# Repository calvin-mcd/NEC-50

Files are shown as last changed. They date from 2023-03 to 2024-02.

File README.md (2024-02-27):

# NEC-50

NEC-50 is a katana stagger keyboard pcb using the micro controller [rp2040-zero](https://www.waveshare.com/rp2040-zero.htm) and taking heavy inspiration from the [NEC PC-9801](http://xahlee.info/kbd/nec_m_type_1992.html)

## Layout

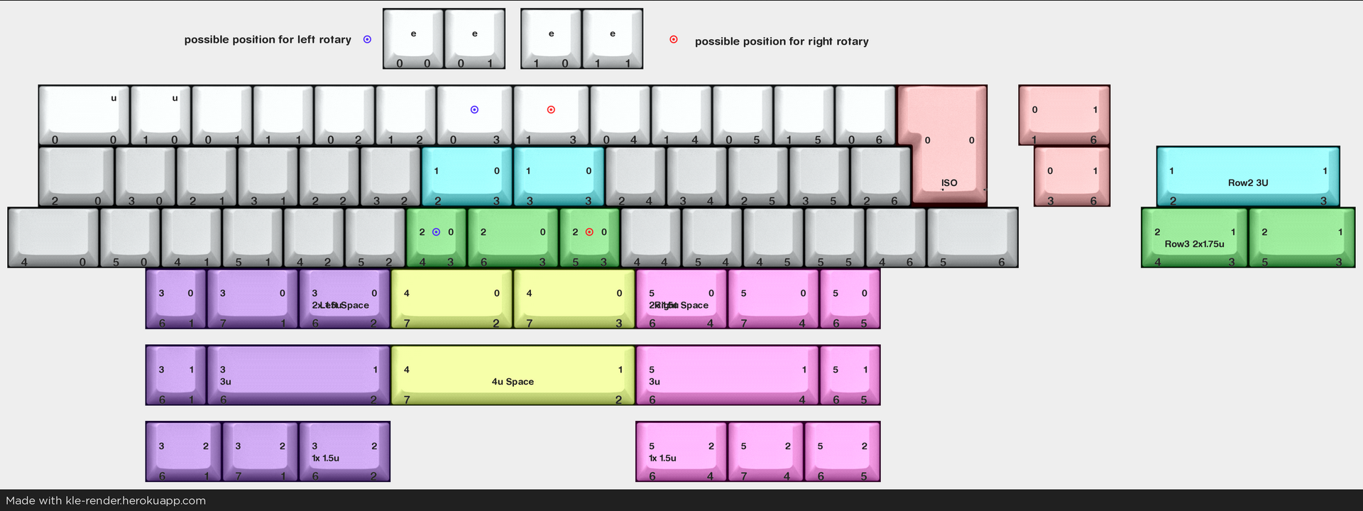
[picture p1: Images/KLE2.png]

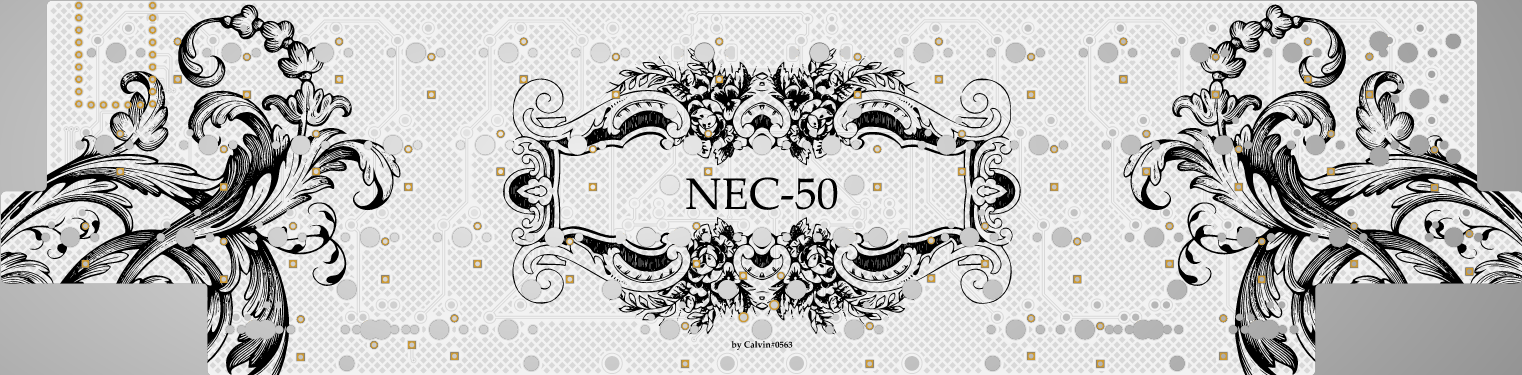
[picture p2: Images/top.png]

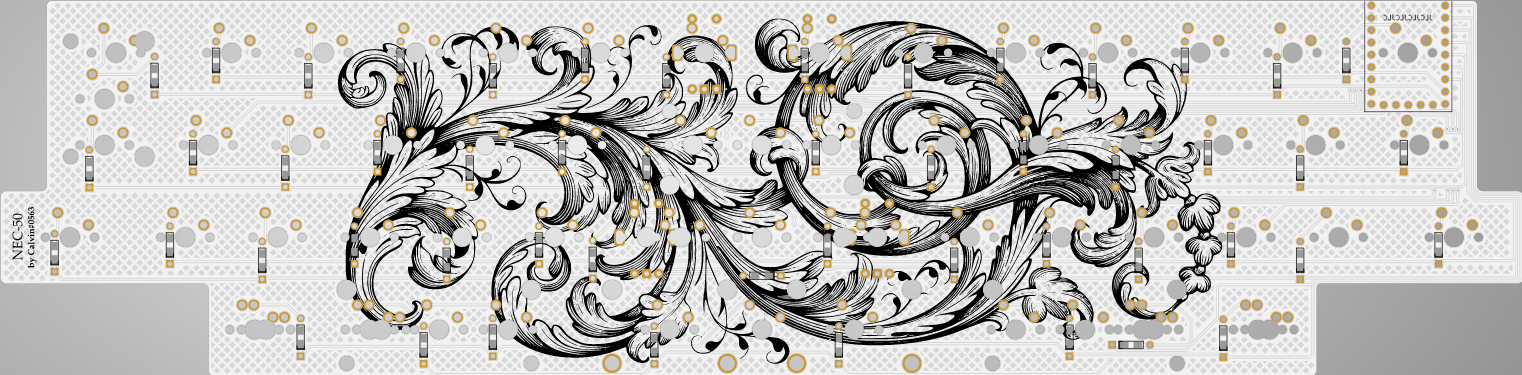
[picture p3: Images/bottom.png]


[Link](http://www.keyboard-layout-editor.com/#/gists/75caf7895b6885905f6ad9112279089a)

## Cases

There are two cases for the NEC-50 so far:

- BAonDiscord#7634's custom case is called the N0550 and takes inspiration from the M0110.



https://github.com/ba-keyboards/N0550

check out their other amazing cases here: https://ba-keyboards.github.io/

- dingusaurusderp's case is called the Hotdog stand (lol) and is a two piece and can also support a weight if desired!

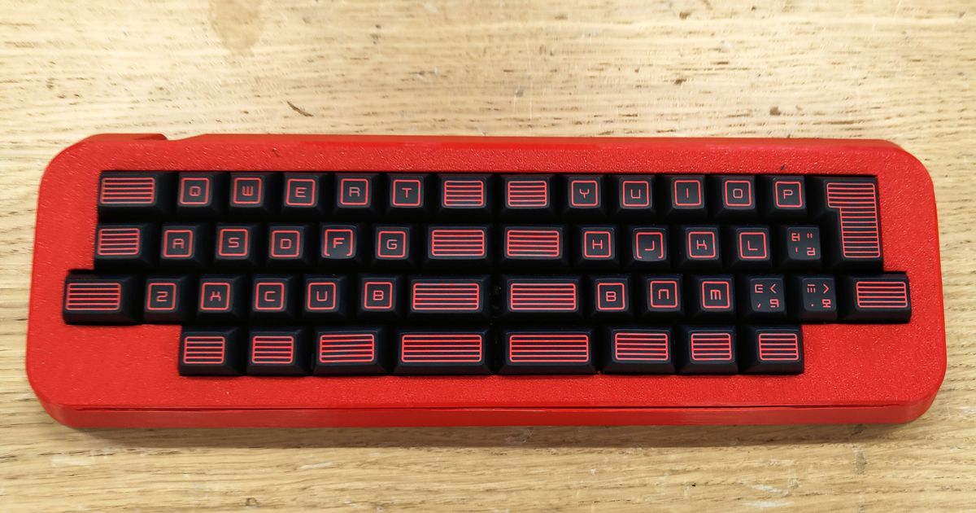
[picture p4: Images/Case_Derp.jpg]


https://www.printables.com/de/model/784448-hotdog-stand-nec-50-case
  
## Disclaimer

The PCB and case files has been fully tested and confirmed to work. The members of the PCB development team are however not liable if you end up with a non-functional pcb. Order at your own risk. Support will not be provided but pull requests will be reviewed and possibly accepted.

## License

This project is released under the GPL v3 License. Please refer to the LICENCE file.

## Credits

big thanks to both BAonDiscord#7634 and dingusaurusderp for taking their time to create unqiue cases for something that started out as more of a joke! love the 40s community!

also many thanks to haizeus for helping with the KLE and firmware!

As always big thanks also to the many people who inspired and helped with this board!

Any questions, contact Calvin\#0563 on Discord.

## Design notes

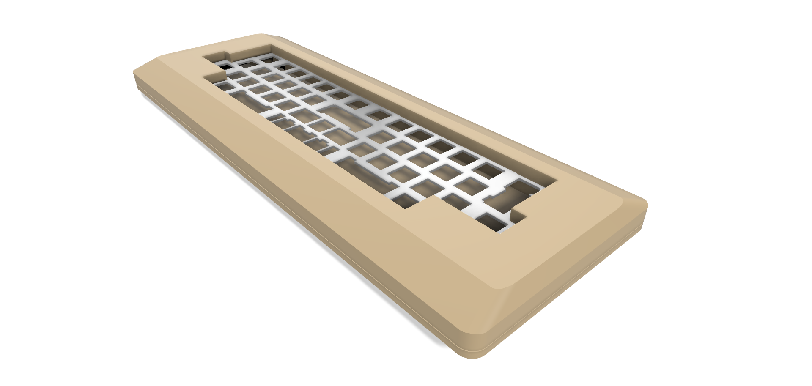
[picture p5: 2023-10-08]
Images/Case - M0110 - 1.png

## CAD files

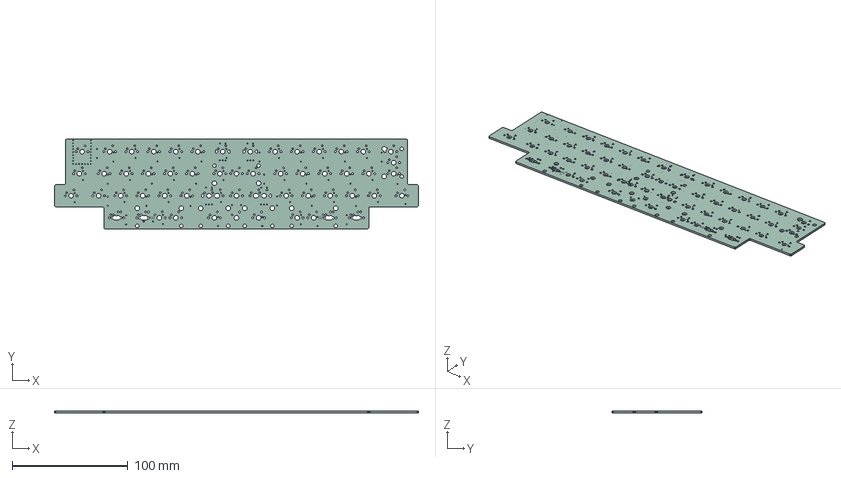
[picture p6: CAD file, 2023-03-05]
Project/NEC.step
314.3 x 77.5 x 1.60 mm

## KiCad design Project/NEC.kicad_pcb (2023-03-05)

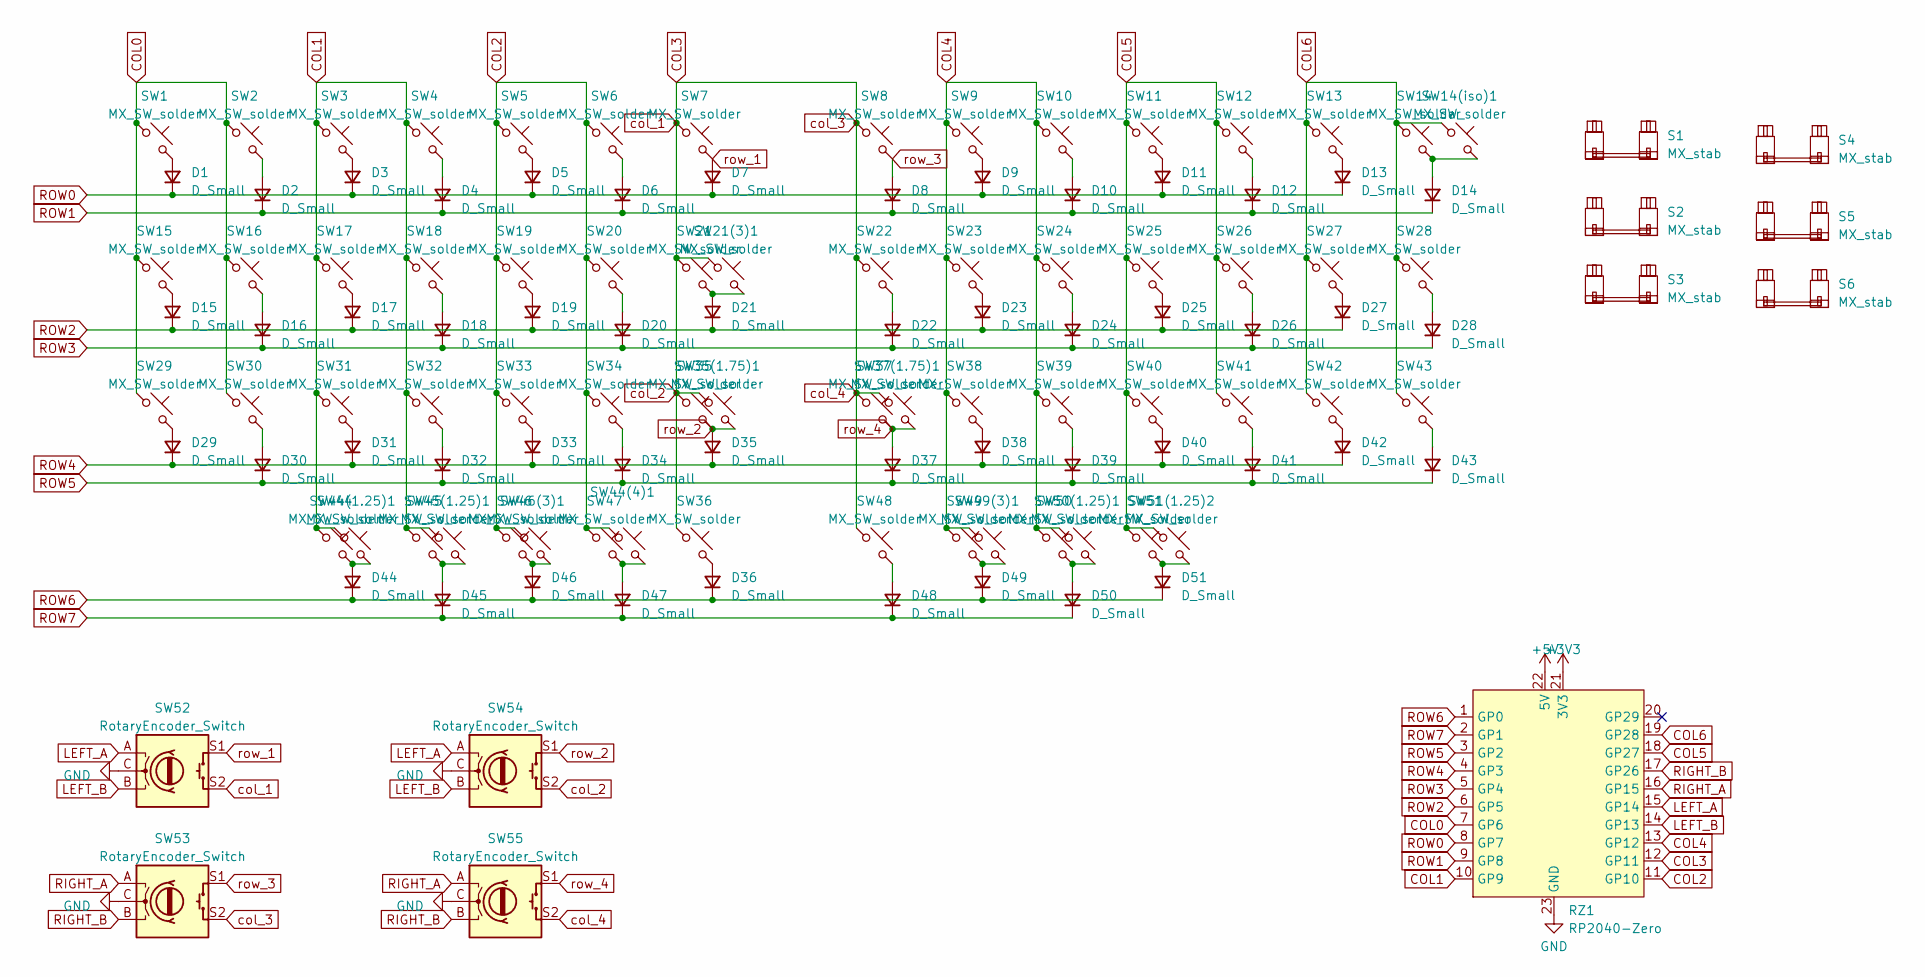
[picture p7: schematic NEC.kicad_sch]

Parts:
D1, D2, D3, D4, D5, D6, D7, D8, D9, D10, D11, D12, D13, D14, D15, D16, D17, D18, D19, D20, D21, D22, D23, D24, D25, D26, D27, D28, D29, D30, D31, D32, D33, D34, D35, D36, D37, D38, D39, D40, D41, D42, D43, D44, D45, D46, D47, D48, D49, D50, D51: D_Small; Diode-Hybrid-Back
RZ1: RP2040-Zero
S1, S2: MX_stab; STAB_MX_P_2u
S3, S4, S5: MX_stab; STAB_MX_3u
S6: MX_stab; STAB_MX_ISO_FLIPPED
SW1, SW14, SW21, SW22, SW29, SW36, SW43, SW45, SW46, SW49, SW50: MX_SW_solder; SW_MX_1.5u
SW2, SW3, SW4, SW5, SW6, SW9, SW10, SW11, SW12, SW13, SW14(iso)1, SW16, SW17, SW18, SW19, SW20, SW21(3)1, SW23, SW24, SW25, SW26, SW27, SW30, SW31, SW32, SW33, SW34, SW35, SW37, SW38, SW39, SW40, SW41, SW42, SW44, SW46(3)1, SW47, SW48, SW49(3)1, SW51: MX_SW_solder; SW_MX_1u
SW7, SW8, SW15, SW28, SW44(1.25)1, SW45(1.25)1, SW50(1.25)1, SW51(1.25)2: MX_SW_solder; SW_MX_1.25u
SW35(1.75)1, SW37(1.75)1: MX_SW_solder; SW_MX_1.75u
SW44(4)1: SW_Push_45deg; CherryMX_4.00u
SW52, SW53, SW54, SW55: RotaryEncoder_Switch; ROT_Alps_EC11E-Switch

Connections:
+3V3: RZ1.21 (3V3)
+5V: RZ1.22 (5V)
COL0: RZ1.7 (GP6), SW1.1, SW2.1, SW15.1, SW16.1, SW29.1, SW30.1
COL1: RZ1.10 (GP9), SW3.1, SW4.1, SW17.1, SW18.1, SW31.1, SW32.1, SW44.1, SW44(1.25)1.1, SW45.1, SW45(1.25)1.1
COL2: RZ1.11 (GP10), SW5.1, SW6.1, SW19.1, SW20.1, SW33.1, SW34.1, SW44(4)1.1, SW46.1, SW46(3)1.1, SW47.1
COL3: RZ1.12 (GP11), SW7.1, SW8.1, SW21.1, SW21(3)1.1, SW22.1, SW35.1, SW35(1.75)1.1, SW36.1, SW37.1, SW37(1.75)1.1, SW48.1, SW52.S2, SW53.S2, SW54.S2, SW55.S2
COL4: RZ1.13 (GP12), SW9.1, SW10.1, SW23.1, SW24.1, SW38.1, SW39.1, SW49.1, SW49(3)1.1, SW50.1, SW50(1.25)1.1
COL5: RZ1.18 (GP27), SW11.1, SW12.1, SW25.1, SW26.1, SW40.1, SW41.1, SW51.1, SW51(1.25)2.1
COL6: RZ1.19 (GP28), SW13.1, SW14.1, SW14(iso)1.1, SW27.1, SW28.1, SW42.1, SW43.1
GND: RZ1.23 (GND), SW52.C, SW53.C, SW54.C, SW55.C
LEFT_A: RZ1.15 (GP14), SW52.A, SW54.A
LEFT_B: RZ1.14 (GP13), SW52.B, SW54.B
unnamed: D1.2 (A), SW1.2
unnamed: D2.2 (A), SW2.2
unnamed: D3.2 (A), SW3.2
unnamed: D4.2 (A), SW4.2
unnamed: D5.2 (A), SW5.2
unnamed: D6.2 (A), SW6.2
unnamed: D9.2 (A), SW9.2
unnamed: D10.2 (A), SW10.2
unnamed: D11.2 (A), SW11.2
unnamed: D12.2 (A), SW12.2
unnamed: D13.2 (A), SW13.2
unnamed: D14.2 (A), SW14.2, SW14(iso)1.2
unnamed: D15.2 (A), SW15.2
unnamed: D16.2 (A), SW16.2
unnamed: D17.2 (A), SW17.2
unnamed: D18.2 (A), SW18.2
unnamed: D19.2 (A), SW19.2
unnamed: D20.2 (A), SW20.2
unnamed: D21.2 (A), SW21.2, SW21(3)1.2
unnamed: D22.2 (A), SW22.2
unnamed: D23.2 (A), SW23.2
unnamed: D24.2 (A), SW24.2
unnamed: D25.2 (A), SW25.2
unnamed: D26.2 (A), SW26.2
unnamed: D27.2 (A), SW27.2
unnamed: D28.2 (A), SW28.2
unnamed: D29.2 (A), SW29.2
unnamed: D30.2 (A), SW30.2
unnamed: D31.2 (A), SW31.2
unnamed: D32.2 (A), SW32.2
unnamed: D33.2 (A), SW33.2
unnamed: D34.2 (A), SW34.2
unnamed: D36.2 (A), SW36.2
unnamed: D38.2 (A), SW38.2
unnamed: D39.2 (A), SW39.2
unnamed: D40.2 (A), SW40.2
unnamed: D41.2 (A), SW41.2
unnamed: D42.2 (A), SW42.2
unnamed: D43.2 (A), SW43.2
unnamed: D44.2 (A), SW44.2, SW44(1.25)1.2
unnamed: D45.2 (A), SW45.2, SW45(1.25)1.2
unnamed: D46.2 (A), SW46.2, SW46(3)1.2
unnamed: D47.2 (A), SW44(4)1.2, SW47.2
unnamed: D48.2 (A), SW48.2
unnamed: D49.2 (A), SW49.2, SW49(3)1.2
unnamed: D50.2 (A), SW50.2, SW50(1.25)1.2
unnamed: D51.2 (A), SW51.2, SW51(1.25)2.2
RIGHT_A: RZ1.16 (GP15), SW53.A, SW55.A
RIGHT_B: RZ1.17 (GP26), SW53.B, SW55.B
ROW0: D1.1 (K), D3.1 (K), D5.1 (K), D7.1 (K), D9.1 (K), D11.1 (K), D13.1 (K), RZ1.8 (GP7)
ROW1: D2.1 (K), D4.1 (K), D6.1 (K), D8.1 (K), D10.1 (K), D12.1 (K), D14.1 (K), RZ1.9 (GP8)
ROW2: D15.1 (K), D17.1 (K), D19.1 (K), D21.1 (K), D23.1 (K), D25.1 (K), D27.1 (K), RZ1.6 (GP5)
ROW3: D16.1 (K), D18.1 (K), D20.1 (K), D22.1 (K), D24.1 (K), D26.1 (K), D28.1 (K), RZ1.5 (GP4)
ROW4: D29.1 (K), D31.1 (K), D33.1 (K), D35.1 (K), D38.1 (K), D40.1 (K), D42.1 (K), RZ1.4 (GP3)
ROW5: D30.1 (K), D32.1 (K), D34.1 (K), D37.1 (K), D39.1 (K), D41.1 (K), D43.1 (K), RZ1.3 (GP2)
ROW6: D36.1 (K), D44.1 (K), D46.1 (K), D49.1 (K), D51.1 (K), RZ1.1 (GP0)
ROW7: D45.1 (K), D47.1 (K), D48.1 (K), D50.1 (K), RZ1.2 (GP1)
row_1: D7.2 (A), SW7.2, SW52.S1
row_2: D35.2 (A), SW35.2, SW35(1.75)1.2, SW54.S1
row_3: D8.2 (A), SW8.2, SW53.S1
row_4: D37.2 (A), SW37.2, SW37(1.75)1.2, SW55.S1

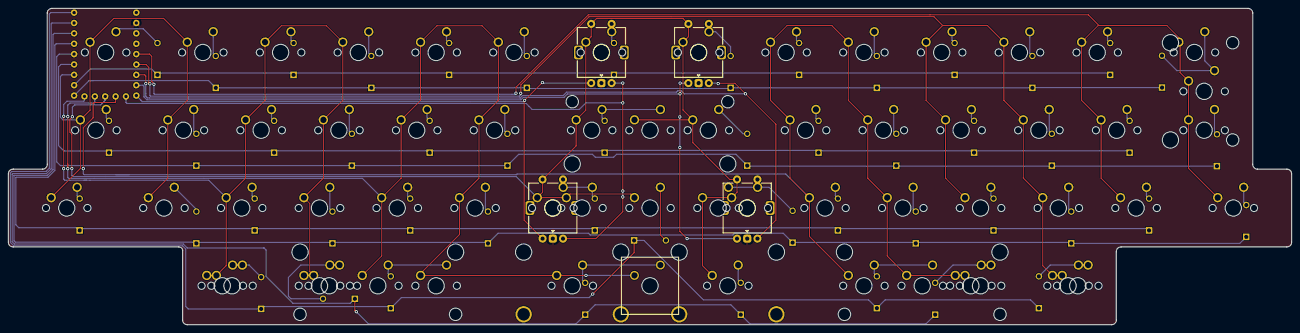
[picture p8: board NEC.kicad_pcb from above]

Board: 2 copper layers, 314.3 x 77.5 mm, 124 parts (1 on the bottom side), 71 nets.

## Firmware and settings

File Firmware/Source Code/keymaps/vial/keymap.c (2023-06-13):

/* SPDX-License-Identifier: GPL-2.0-or-later */

#include QMK_KEYBOARD_H

const uint16_t PROGMEM keymaps[][MATRIX_ROWS][MATRIX_COLS] = {

	[0] = LAYOUT(
		KC_TRNS, KC_TRNS, KC_TRNS, KC_TRNS, KC_TRNS, KC_TRNS, KC_TRNS, KC_TRNS, KC_TRNS, KC_TRNS, KC_TRNS, KC_TRNS, KC_TRNS, KC_TRNS,
		KC_TRNS, KC_TRNS, KC_TRNS, KC_TRNS, KC_TRNS, KC_TRNS, KC_TRNS, KC_TRNS, KC_TRNS, KC_TRNS, KC_TRNS, KC_TRNS, KC_TRNS, KC_TRNS,
		KC_TRNS, KC_TRNS, KC_TRNS, KC_TRNS, KC_TRNS, KC_TRNS, KC_TRNS, KC_TRNS, KC_TRNS, KC_TRNS, KC_TRNS, KC_TRNS, KC_TRNS, KC_TRNS,
		KC_TRNS, KC_TRNS, KC_TRNS, KC_TRNS, KC_TRNS, KC_TRNS, KC_TRNS, KC_TRNS, KC_TRNS
	),

	[1] = LAYOUT(
		KC_TRNS, KC_TRNS, KC_TRNS, KC_TRNS, KC_TRNS, KC_TRNS, KC_TRNS, KC_TRNS, KC_TRNS, KC_TRNS, KC_TRNS, KC_TRNS, KC_TRNS, KC_TRNS,
		KC_TRNS, KC_TRNS, KC_TRNS, KC_TRNS, KC_TRNS, KC_TRNS, KC_TRNS, KC_TRNS, KC_TRNS, KC_TRNS, KC_TRNS, KC_TRNS, KC_TRNS, KC_TRNS,
		KC_TRNS, KC_TRNS, KC_TRNS, KC_TRNS, KC_TRNS, KC_TRNS, KC_TRNS, KC_TRNS, KC_TRNS, KC_TRNS, KC_TRNS, KC_TRNS, KC_TRNS, KC_TRNS,
		KC_TRNS, KC_TRNS, KC_TRNS, KC_TRNS, KC_TRNS, KC_TRNS, KC_TRNS, KC_TRNS, KC_TRNS
	),

	[2] = LAYOUT(
		KC_TRNS, KC_TRNS, KC_TRNS, KC_TRNS, KC_TRNS, KC_TRNS, KC_TRNS, KC_TRNS, KC_TRNS, KC_TRNS, KC_TRNS, KC_TRNS, KC_TRNS, KC_TRNS,
		KC_TRNS, KC_TRNS, KC_TRNS, KC_TRNS, KC_TRNS, KC_TRNS, KC_TRNS, KC_TRNS, KC_TRNS, KC_TRNS, KC_TRNS, KC_TRNS, KC_TRNS, KC_TRNS,
		KC_TRNS, KC_TRNS, KC_TRNS, KC_TRNS, KC_TRNS, KC_TRNS, KC_TRNS, KC_TRNS, KC_TRNS, KC_TRNS, KC_TRNS, KC_TRNS, KC_TRNS, KC_TRNS,
		KC_TRNS, KC_TRNS, KC_TRNS, KC_TRNS, KC_TRNS, KC_TRNS, KC_TRNS, KC_TRNS, KC_TRNS
	),

	[3] = LAYOUT(
		KC_TRNS, KC_TRNS, KC_TRNS, KC_TRNS, KC_TRNS, KC_TRNS, KC_TRNS, KC_TRNS, KC_TRNS, KC_TRNS, KC_TRNS, KC_TRNS, KC_TRNS, KC_TRNS,
		KC_TRNS, KC_TRNS, KC_TRNS, KC_TRNS, KC_TRNS, KC_TRNS, KC_TRNS, KC_TRNS, KC_TRNS, KC_TRNS, KC_TRNS, KC_TRNS, KC_TRNS, KC_TRNS,
		KC_TRNS, KC_TRNS, KC_TRNS, KC_TRNS, KC_TRNS, KC_TRNS, KC_TRNS, KC_TRNS, KC_TRNS, KC_TRNS, KC_TRNS, KC_TRNS, KC_TRNS, KC_TRNS,
		KC_TRNS, KC_TRNS, KC_TRNS, KC_TRNS, KC_TRNS, KC_TRNS, KC_TRNS, KC_TRNS, KC_TRNS
	),

};


/* `ENCODER_MAP_ENABLE = yes` must be added to the rules.mk at the KEYMAP level. See QMK docs. */
/* Remove the following code if you do not enable it in your keymap (e.g. default keymap). */
#if defined(ENCODER_MAP_ENABLE)
const uint16_t PROGMEM encoder_map[][NUM_ENCODERS][2] = {
	[0] = { ENCODER_CCW_CW(KC_TRNS, KC_TRNS), ENCODER_CCW_CW(KC_TRNS, KC_TRNS) },
	[1] = { ENCODER_CCW_CW(KC_TRNS, KC_TRNS), ENCODER_CCW_CW(KC_TRNS, KC_TRNS) },
	[2] = { ENCODER_CCW_CW(KC_TRNS, KC_TRNS), ENCODER_CCW_CW(KC_TRNS, KC_TRNS) },
	[3] = { ENCODER_CCW_CW(KC_TRNS, KC_TRNS), ENCODER_CCW_CW(KC_TRNS, KC_TRNS) }
};
#endif

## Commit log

2023-03-05 1st draft compete
    [NEC-B_Cu.gbr, NEC-B_Mask.gbr, NEC-B_Paste.gbr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]
2023-03-05 organised folders
    [NEC.kicad_pcb, NEC.kicad_sch]
2023-03-05 silkscreen, aesthetics, new production files
    [NEC-B_Cu.gbr, NEC-B_Mask.gbr, NEC-B_Paste.gbr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]
2023-03-05 clear up production files
    [NEC-B_Cu.gbr, NEC-B_Mask.gbr, NEC-B_Paste.gbr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]
2023-03-10 silkscreen revision, some routing cleaning
    [NEC-B_Cu.gbr, NEC-B_Mask.gbr, NEC-B_Paste.gbr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]
2023-03-10 small silkscreen change
2023-04-22 jlcjlc text added, new production files
    [NEC-B_Cu.gbr, NEC-B_Mask.gbr, NEC-B_Paste.gbr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]
2023-05-17 fresh gerbers
    [NEC-B_Cu.gbr, NEC-B_Mask.gbr, NEC-B_Paste.gbr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]
2023-05-31 added 5 pin support for 4u centre switch
2023-10-08 Create Case - M0110 - 1.png
2024-02-27 new case link added to readme
2024-02-27 clearer labelling on THT diodes & fresh gerbers
    [NEC-B_Cu.gbr, NEC-B_Mask.gbr, NEC-B_Paste.gbr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]
